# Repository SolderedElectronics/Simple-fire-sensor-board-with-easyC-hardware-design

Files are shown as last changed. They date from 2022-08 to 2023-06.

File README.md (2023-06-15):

## Simple fire sensor board with easyC Hardware design

| Product name |
| :----------------------------------------------------------: |
|      [Buy Simple fire sensor board with easyC](https://www.solde.red/333042)      |

On this module there is a component, a phototransistor, which is capable of detecting infrared radiation. Since fire emits a large amount of infrared radiation, this sensor will detect it, but that is not its only application. Wherever there are IR (infra-red) waves, this sensor will detect them, including solar radiation.

The simple sensor comes with easyC connectors onboard, which enables quick and easy connection with the microcontroller.

## Repository contents

All Soldered hardware is designed in KiCAD, and repositories are organized in the following way:

- CAD folder - contains KiCAD files (Schematics, Board, Panel Board), organized by version. Change log lists all changes between versions.
- OUTPUTS - contains useful files, such as Bill of Materials (BOM), PDF of schematics, 3D .step file of the board and gerber files, organized by version. 

## Want to contribute?

All contributions are welcome, feel free to submit the pull request. If you discover a bug, please submit an issue or pull request. 

## About Soldered

Soldered logo

At Soldered, we design and manufacture a wide selection of electronic products to help you turn your ideas into acts and bring you one step closer to your final project. Our products are intented for makers and crafted in-house by our experienced team in Osijek, Croatia. We believe that sharing is a crucial element for improvement and innovation, and we work hard to stay connected with all our makers regardless of their skill or experience level. Therefore, all our products are open-source. Finally, we always have your back. If you face any problem concerning either your shopping experience or your electronics project, our team will help you deal with it, offering efficient customer service and cost-free technical support anytime. Some of those might be useful for you:

- [Web Store](https://www.soldered.com)
- [Tutorials & Projects](https://learn.soldered.com)
- [Community & Technical support](https://community.soldered.com)
- [Custom PCBs](https://pcb.soldered.com)

## License info

All Soldered open-source hardware (OSH) is under The TAPR Open Hardware License. Read more in the LICENSE file. 

No warranty - all designs in this repository are distributed in the hope that they will be useful, but without any warranty. They are provided "AS IS", therefore without warranty of any kind, either expressed or implied. The entire quality and performance of what you do with the contents of this repository are your responsibility. In no event, Soldered (TAVU) will be liable for your damages, losses, including any general, special, incidental or consequential damage arising out of the use or inability to use the contents of this repository. 

Thank you from your fellow makers at Soldered.

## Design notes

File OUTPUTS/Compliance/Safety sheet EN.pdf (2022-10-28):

## Regulatory Compliance and Important Safety Information

PLEASE RETAIN THIS INFORMATION FOR FUTURE REFERENCE.

BEFORE USING THIS PRODUCT, READ ALL INSTRUCTION IN THIS DOCUMENT.

Product name: | Simple fire sensor board with easyC
Getting started: | To get started, please visit www.soldered.com

# WARNINGS

- This product should not be covered and should be operated in well ventilated enviroment.
- The product should be placed on a stable, flat, non-conductive surface and should not be contacted by conductive items.
- Connection of other devices may affect compliance or result in damage to the unit, and invalidate the warranty.
- Where peripherals are connected that do not include the cable or connector, the cable or connector used must offer adequate insulation and operation in order that the requirements of the relevant performance and safety requirements are met.
- There is a danger of explosion if the battery is incorrectly placed.
- The product should not be used outside of its specified working range.

# INSTRUCTIONS FOR SAFE USE

To avoid malfunction or damage to your device, please observe the following:
- Do not expose it to water, moisture or place on a conductive surface when turned on. Do not handle the unit with wet hands.
- Do not expose it to heat from any source; the product is designed to be used at normal ambient room temperatures. The product is intended to be used inside.
- Take care when handling to avoid mechanical or electrical damage to any part of the unit. Avoid handling the unit while it's powered. Use ESD protection.
- Use only supplied cable (or the cable of the same or higher quality) with the unit.

# COMPLIANCE INFORMATION

The product complies with the relevant provision of the RoHS Directive for the European Union. In common with all Electrical and Electronic Equipment (EEE), the product should not be disposed household waste.

ELECTROMAGNETIC COMPABILITY AND OPERATION

- The product is in conformity with the protection requirements of EU Council Directive 2014/30/EU on the laws of the Member States relating of electromagnetic compability, and Electromagnetic Compability Regulations 2016 of the UK.
- WARNING: Please do not alter the design of this product, doing so may void your ability to use the product freely, this includes altering the frequency at which product operates.

Soldered Electronics d.o.o., Reisnerova ulica 100, 31000 Osijek, Croatia. VAT ID: HR83200237288

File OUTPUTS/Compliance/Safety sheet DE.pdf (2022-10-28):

## Einhaltung gesetzlicher Vorschriften und wichtige Sicherheitsinformationen

BITTE BEWAHREN SIE DIESE INFORMATIONEN ZUR SPÄTEREN VERWENDUNG AUF.

LESEN SIE VOR DER VERWENDUNG DIESES PRODUKTS ALLE ANWEISUNGEN IN DOKUMENT.

Produktname: | Simple fire sensor board with easyC
Die ersten Schritte: | Besuchen Sie www.soldered.com, um loszulegen.

# WARNUNGEN

- Dieses Produkt sollte nicht abgedeckt werden und in einer gut belüfteten Umgebung betrieben werden.
- Das Produkt sollte auf einer stabilen, flachen, nicht leitenden Oberfläche aufgestellt werden und nicht mit leitenden Gegenständen in Berührung kommen.
- Der Anschluss anderer Geräte kann die Konformität beeinträchtigen oder zu Schäden am Gerät führen und zum Erlöschen der Garantie führen.
- Wenn Peripheriegeräte angeschlossen werden, die nicht das Kabel oder den Stecker enthalten, muss das verwendete Kabel oder muss das verwendete Kabel bzw. der verwendete Steckverbinder eine angemessene Isolierung und Funktion aufweisen, damit die Anforderungen die einschlägigen Leistungs- und Sicherheitsanforderungen erfüllt werden.
- Es besteht Explosionsgefahr, wenn die Batterie falsch eingesetzt wird.
- Das Produkt sollte nicht außerhalb des angegebenen Arbeitsbereichs verwendet werden.

# HINWEISE ZUR SICHEREN ANWENDUNG

Um Fehlfunktionen oder Schäden an Ihrem Gerät zu vermeiden, beachten Sie bitte die folgenden Hinweise:
- Setzen Sie das Gerät nicht Wasser oder Feuchtigkeit aus und stellen Sie es nicht auf eine
leitende Oberfläche, wenn es eingeschaltet ist. Das Gerät nicht mit nassen Händen anfassen.
- Setzen Sie es keiner Wärmequelle aus; das Produkt ist für die Verwendung bei normalen Raumtemperaturen ausgelegt. Das Produkt ist für die Verwendung in Innenräumen vorgesehen.
- Seien Sie bei der Handhabung vorsichtig, um mechanische oder elektrische Schäden an Teilen des Geräts zu vermeiden. Fassen Sie das Gerät nicht an, wenn es unter Spannung steht. Verwenden Sie einen ESD-Schutz.
- Verwenden Sie nur das mitgelieferte Kabel (oder ein gleich- oder höherwertiges Kabel)
mit dem Gerät.

# COMPLIANCE-INFORMATIONEN

Das Produkt entspricht den entsprechenden Bestimmungen der RoHS-Richtlinie für die Europäische Union. Wie alle elektrischen und elektronischen Geräte (EEE), sollte das Produkt nicht über den Hausmüll entsorgt werden.
ELEKTROMAGNETISCHE VERTRÄGLICHKEIT UND BETRIEB
- Das Produkt entspricht den Schutzanforderungen der Richtlinie des EU-Rates 2014/30/EU über die Rechtsvorschriften der Mitgliedstaaten zur elektromagnetischen Verträglichkeit und den Elektromagnetische Verträglichkeitsverordnung 2016 des Vereinigten Königreichs.
- WARNUNG: Bitte verändern Sie nicht das Design dieses Produkts, da dies dazu führen kann, dass Sie das Produkt nicht mehr uneingeschränkt nutzen können.
Dies gilt auch für die Änderung der Frequenz, mit der das Produkt arbeitet.

Soldered Electronics d.o.o., Reisnerova ulica 100, 31000 Osijek, Croatia. VAT ID: HR83200237288

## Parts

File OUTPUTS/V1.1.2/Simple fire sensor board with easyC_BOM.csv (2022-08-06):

Id | Designator | Package | Quantity | Designation | Supplier and ref
1 | K3,K5 | easyC-connector | 2 | easyC-SMD
2 | R3,R4,R1 | 0603R | 3 | 10k
3 | K4 | HEADER-UPDI | 1 | HEADER-UPDI
4 | FD1 | FIDUCIAL_23 | 1 | FIDUCIAL
5 | D1 | 0402LED | 1 | purple
6 | K1 | JST-SH_2pin_1mm_C145954 | 1 | JST-SH_2pin_1mm_C145954
7 | H2,H4,H3,H1 | HOLE_3.2mm | 4 | HOLE_3.2mm
8 | R2 | 0402R | 1 | 2k2
9 | U1 | SOIC-14 | 1 | ATTINY404-SSNR
10 | K2 | HEADER_MALE_2X1 | 1 | HEADER_MALE_2X1
11 | C2,C1 | 0603C | 2 | 100n
12 | K6 | DSHP03TS-S | 1 | DSHP03TS-S

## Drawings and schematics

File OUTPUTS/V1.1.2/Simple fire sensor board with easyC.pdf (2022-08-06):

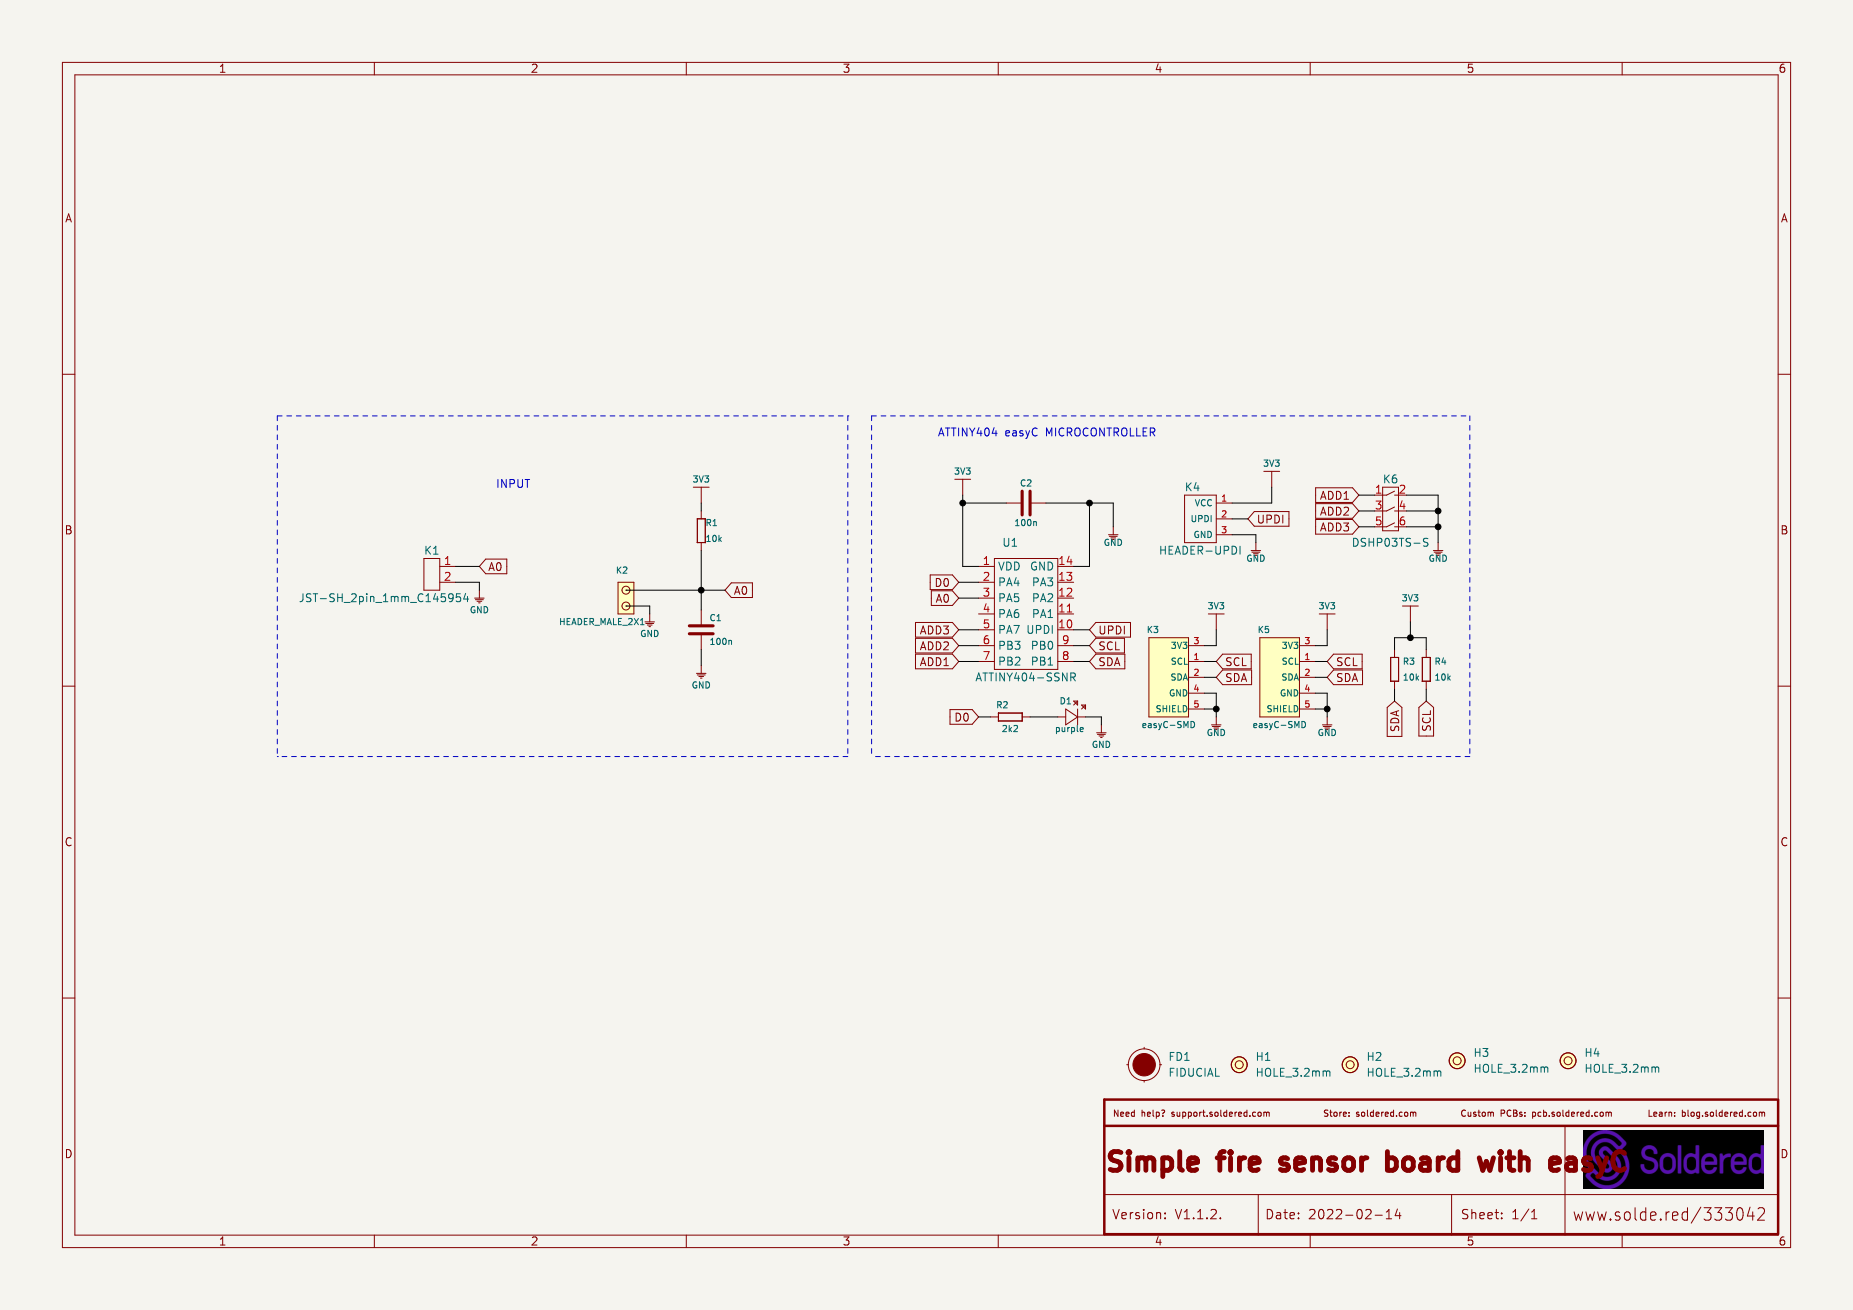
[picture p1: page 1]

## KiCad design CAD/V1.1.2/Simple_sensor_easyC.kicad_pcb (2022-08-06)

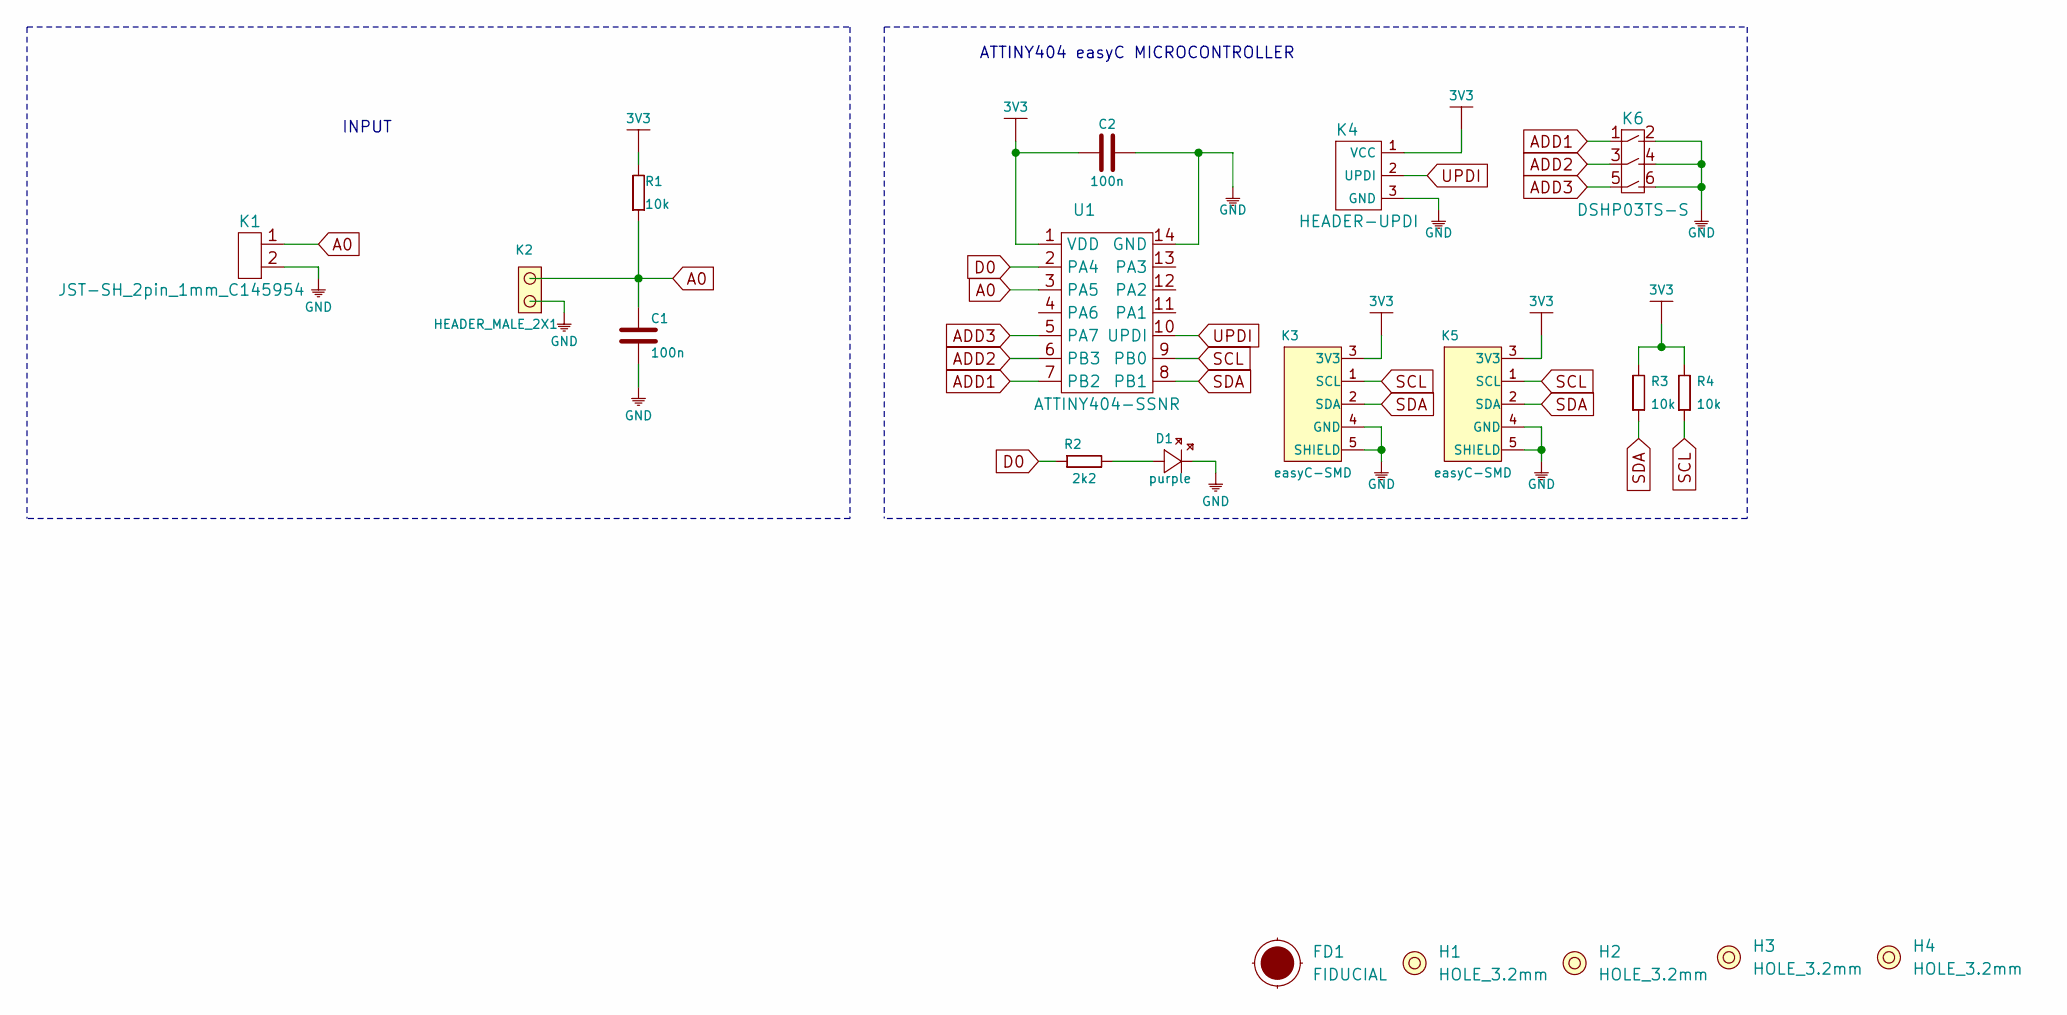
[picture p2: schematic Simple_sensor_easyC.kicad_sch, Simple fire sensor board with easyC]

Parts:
C1, C2: 100n; 0603C
D1: purple; 0402LED
FD1: FIDUCIAL; FIDUCIAL_23
H1, H2, H3, H4: HOLE_3.2mm
K1: JST-SH_2pin_1mm_C145954
K2: HEADER_MALE_2X1
K3, K5: easyC-SMD; easyC-connector
K4: HEADER-UPDI
K6: DSHP03TS-S
R1, R3, R4: 10k; 0603R
R2: 2k2; 0402R
U1: ATTINY404-SSNR; SOIC-14

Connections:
3V3: C2.1, K3.3 (3V3), K4.1 (VCC), K5.3 (3V3), R1.2, R3.2, R4.2, U1.1 (VDD)
A0: C1.2, K1.1, K2.2, R1.1, U1.3 (PA5)
ADD1: K6.1, U1.7 (PB2)
ADD2: K6.3, U1.6 (PB3)
ADD3: K6.5, U1.5 (PA7)
D0: R2.1, U1.2 (PA4)
GND: C1.1, C2.2, D1.2 (K), K1.2, K2.1, K3.4 (GND), K3.5 (SHIELD), K4.3 (GND), K5.4 (GND), K5.5 (SHIELD), K6.2, K6.4, K6.6, U1.14 (GND)
unnamed: D1.1 (A), R2.2
SCL: K3.1 (SCL), K5.1 (SCL), R4.1, U1.9 (PB0)
SDA: K3.2 (SDA), K5.2 (SDA), R3.1, U1.8 (PB1)
UPDI: K4.2 (UPDI), U1.10 (UPDI)

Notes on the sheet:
INPUT
ATTINY404 easyC MICROCONTROLLER

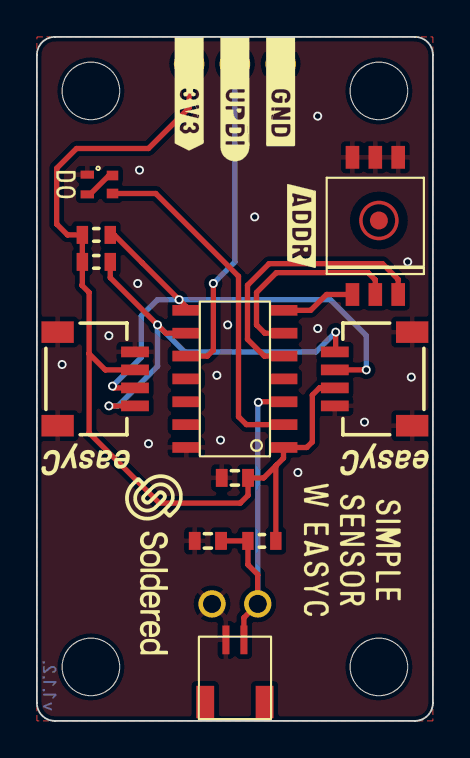
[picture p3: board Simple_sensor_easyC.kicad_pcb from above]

Board: 2 copper layers, 22.0 x 38.0 mm, 19 parts (0 on the bottom side), 11 nets.

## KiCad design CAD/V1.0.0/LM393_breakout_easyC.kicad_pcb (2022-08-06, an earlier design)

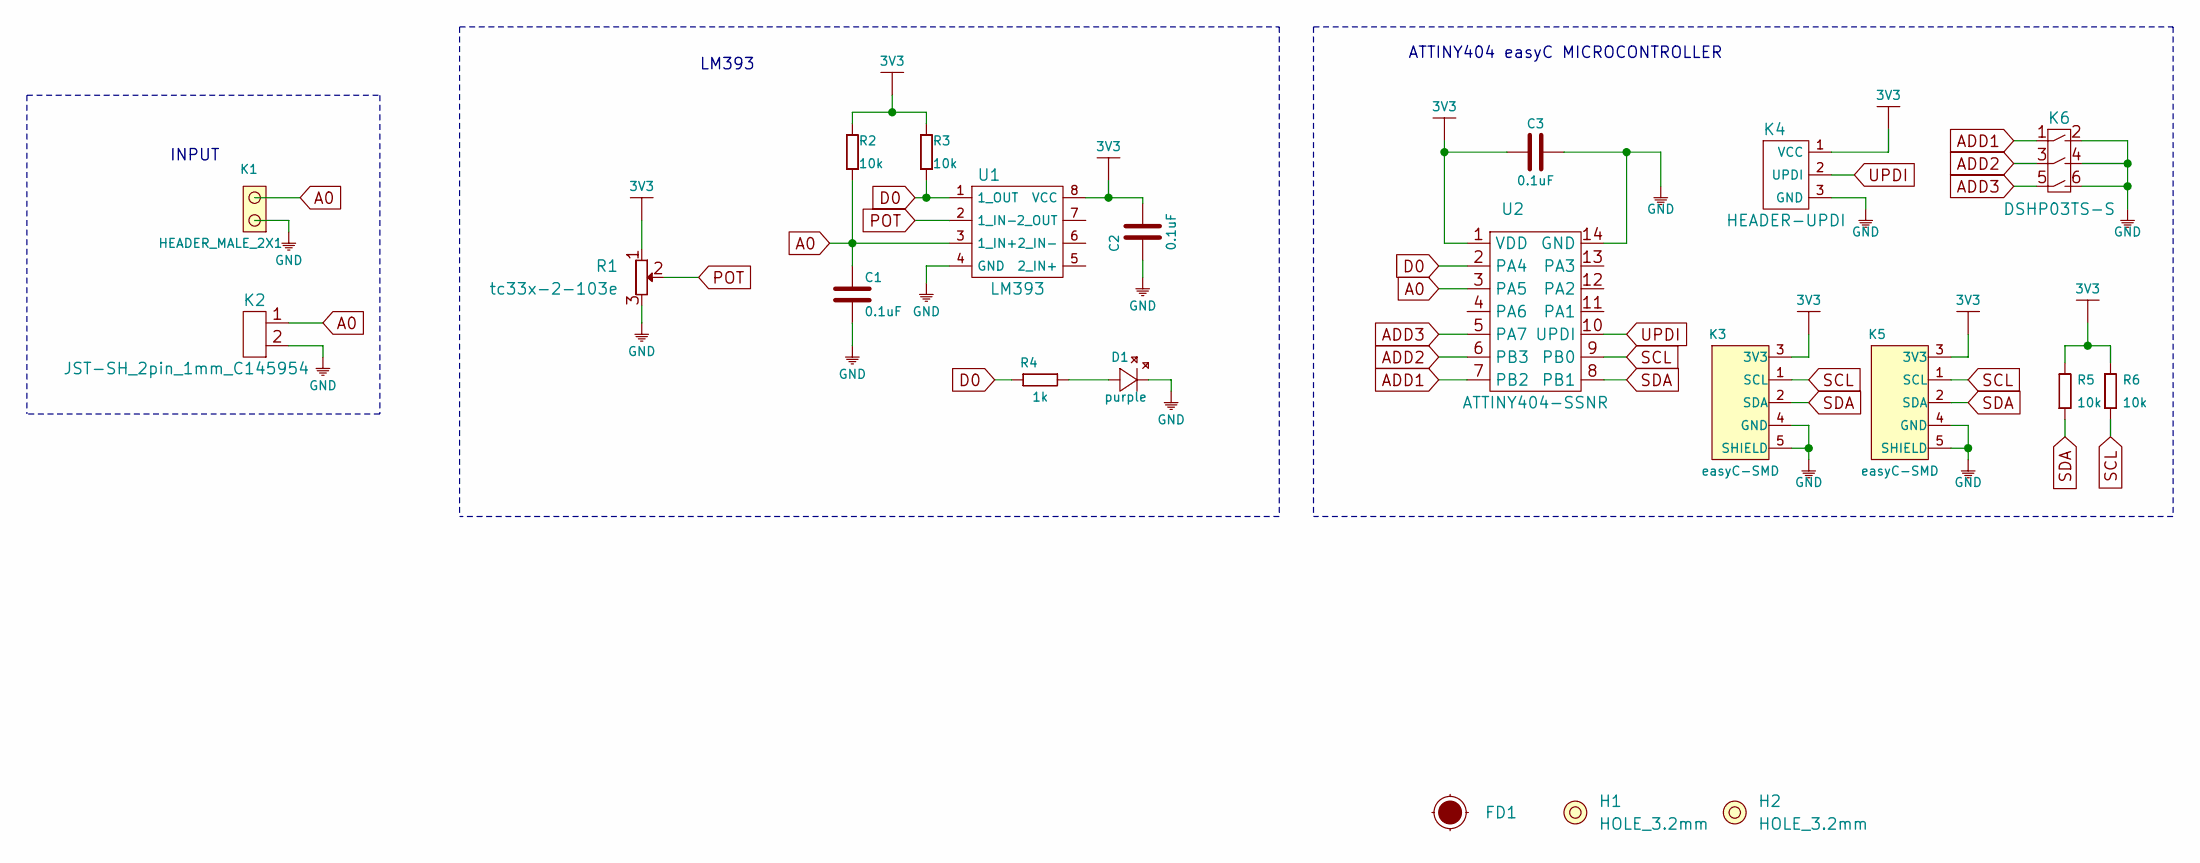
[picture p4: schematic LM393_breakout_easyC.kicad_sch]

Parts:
C1, C2, C3: 0.1uF; 0603C
D1: purple; 0402LED
FD1: Fiducial_Stencil; FIDUCIAL_1MM_PASTE
H1, H2: HOLE_3.2mm
K1: HEADER_MALE_2X1
K2: JST-SH_2pin_1mm_C145954
K3, K5: easyC-SMD; easyC-connector
K4: HEADER-UPDI
K6: DSHP03TS-S
R1: tc33x-2-103e
R2, R3, R5, R6: 10k; 0603R
R4: 1k; 0402R
U1: LM393; SOIC−8
U2: ATTINY404-SSNR; SOIC-14

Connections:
3V3: C2.2, C3.1, K3.3 (3V3), K4.1 (VCC), K5.3 (3V3), R1.1, R2.2, R3.2, R5.2, R6.2, U1.8 (VCC), U2.1 (VDD)
A0: C1.2, K1.2, K2.1, R2.1, U1.3 (1_IN+), U2.3 (PA5)
ADD1: K6.1, U2.7 (PB2)
ADD2: K6.3, U2.6 (PB3)
ADD3: K6.5, U2.5 (PA7)
D0: R3.1, R4.1, U1.1 (1_OUT), U2.2 (PA4)
GND: C1.1, C2.1, C3.2, D1.2 (K), K1.1, K2.2, K3.4 (GND), K3.5 (SHIELD), K4.3 (GND), K5.4 (GND), K5.5 (SHIELD), K6.2, K6.4, K6.6, R1.3, U1.4 (GND), U2.14 (GND)
unnamed: D1.1 (A), R4.2
POT: R1.2, U1.2 (1_IN-)
SCL: K3.1 (SCL), K5.1 (SCL), R6.1, U2.9 (PB0)
SDA: K3.2 (SDA), K5.2 (SDA), R5.1, U2.8 (PB1)
UPDI: K4.2 (UPDI), U2.10 (UPDI)

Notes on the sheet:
INPUT
LM393
ATTINY404 easyC MICROCONTROLLER

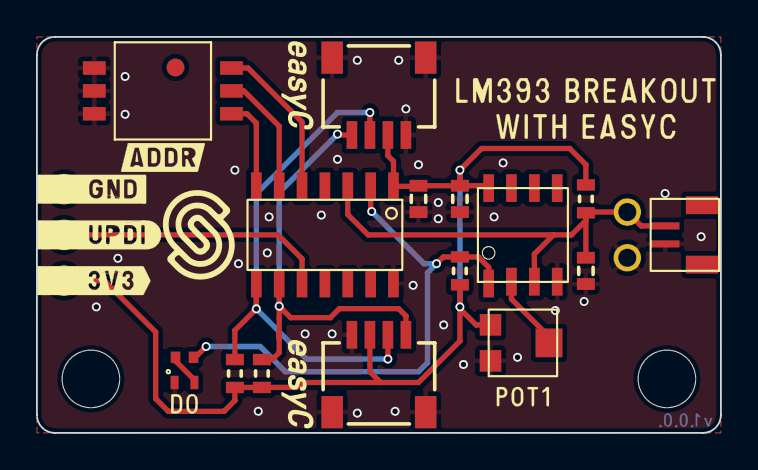
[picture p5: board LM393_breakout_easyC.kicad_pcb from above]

Board: 2 copper layers, 38.0 x 22.0 mm, 21 parts (0 on the bottom side), 12 nets.

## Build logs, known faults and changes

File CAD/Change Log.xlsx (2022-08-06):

CHANGE LOG
 | Latest version |  |  | v1.1.2.
 |  | Product name: |  | Simple fire sensor board with easyC
 |  | Release date: |  | 14.2.2022.
 |  | Release author: |  | Ivan
Version: | v1.0.0. | Author: | Ivan | Date: | 24.5.2021.
List of Changes
 | Initial document
Version: | v1.1.1 | Author: | Ivan | Date: | 5.7.2021.
List of Changes
 | Popravljen footprint za easyC 2 pin SMD konektor
 | Dodana adresa za I2C CUSTOM
 | Stavljen novi fiducial
 | Kvadrati za oznake senzora pomaknuti u stranu od symbola za senzor (zadnja strana)
 | Maknut LM393, koristi se samo MCU
Version: | v1.1.2. | Author: | Ivan | Date: | 14.2.2022.
List of Changes
 | Removed short on SDA and SCL pins on easyC connector
